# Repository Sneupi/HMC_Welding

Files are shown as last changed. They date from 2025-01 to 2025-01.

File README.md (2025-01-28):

# Description

Repo for HMC welding project.

Code is arranged into three files (1 for each device). Arranged as a PlatformIO project for any Pro Mini or UNO (ATMega328P) boards. File `src/main.cpp` indicates which device is to-be-flashed.

Breakout PCBs are located in `kicad`, made with KiCad (8.0) software.

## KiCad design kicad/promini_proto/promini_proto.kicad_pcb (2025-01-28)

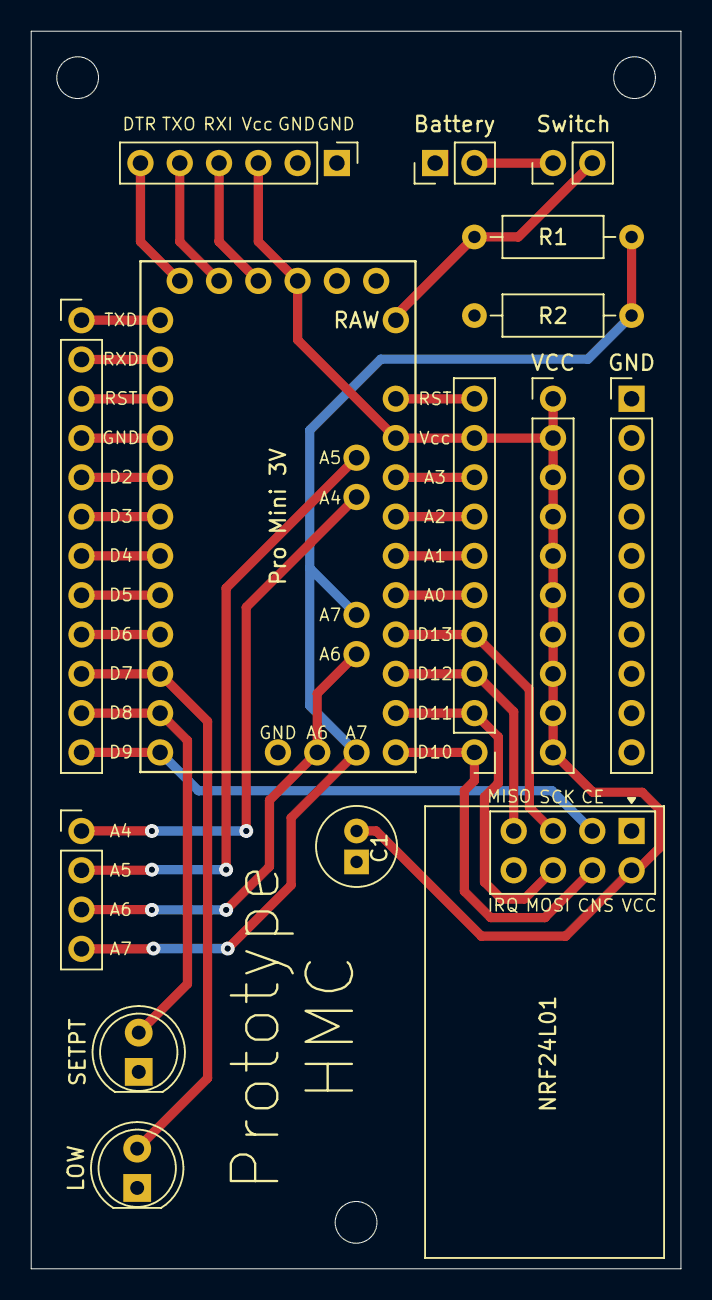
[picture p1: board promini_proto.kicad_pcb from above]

Board: 4 copper layers, 42.0 x 80.0 mm, 15 parts (0 on the bottom side), 31 nets.

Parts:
Battery: Conn_01x02; PinHeader_1x02_P2.54mm_Vertical
C1: C_Polarized; C_Radial_D5.0mm_H11.0mm_P2.00mm
FTDI1: Conn_01x06; PinHeader_1x06_P2.54mm_Vertical
GND: Conn_01x10; PinHeader_1x10_P2.54mm_Vertical
JBottom1: Conn_01x04; PinHeader_1x04_P2.54mm_Vertical
JLeft1: Conn_01x12; PinHeader_1x12_P2.54mm_Vertical
JRight1: Conn_01x10; PinHeader_1x10_P2.54mm_Vertical
LOW: LED; LED_D5.0mm
NRF24L01: NRF24L01_Breakout; nRF24L01_Breakout
Pro Mini 3V: Pro_Mini; Pro_Mini_Universal
R1, R2: R; R_Axial_DIN0207_L6.3mm_D2.5mm_P10.16mm_Horizontal
SETPT: LED; LED_D5.0mm
Switch: Conn_01x02; PinHeader_1x02_P2.54mm_Vertical
VCC: Conn_01x10; PinHeader_1x10_P2.54mm_Vertical

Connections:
A0: JRight1.5, Pro Mini 3V.26 (PC0/A0)
A1: JRight1.6, Pro Mini 3V.25 (PC1/A1)
A2: JRight1.7, Pro Mini 3V.24 (PC2/A2)
A3: JRight1.8, Pro Mini 3V.23 (PC3/A3)
A4: JBottom1.1, Pro Mini 3V.31 (PA4)
A5: JBottom1.2, Pro Mini 3V.32 (PA5)
A6: JBottom1.3, Pro Mini 3V.33 (PA6)
A7: JBottom1.4, Pro Mini 3V.34 (PA7), R1.2, R2.1
D2: JLeft1.5, Pro Mini 3V.11 (PD2)
D3: JLeft1.6, Pro Mini 3V.12 (PD3)
D4: JLeft1.7, Pro Mini 3V.13 (PD4)
D5: JLeft1.8, Pro Mini 3V.14 (PD5)
D6: JLeft1.9, Pro Mini 3V.15 (PD6)
D7: JLeft1.10, LOW.2 (A), Pro Mini 3V.16 (PD7)
D8: JLeft1.11, Pro Mini 3V.17 (PB0), SETPT.2 (A)
D9: JLeft1.12, NRF24L01.3 (CE), Pro Mini 3V.18 (PB1)
D10: JRight1.1, NRF24L01.4 (~CSN), Pro Mini 3V.30 (PB2)
DTR: FTDI1.6, Pro Mini 3V.6 (DTR-CBL)
GND: Battery.1, C1.2, FTDI1.1, FTDI1.2, GND.1, GND.2, GND.3, GND.4, GND.5, GND.6, GND.7, GND.8, GND.9, GND.10, JLeft1.4, LOW.1 (K), NRF24L01.1 (GND), Pro Mini 3V.1 (GND), Pro Mini 3V.2 (GND), Pro Mini 3V.10 (GND), R2.2, SETPT.1 (K)
MISO: JRight1.3, NRF24L01.7 (MISO), Pro Mini 3V.28 (PB4)
MOSI: JRight1.2, NRF24L01.6 (MOSI), Pro Mini 3V.29 (PB3)
unnamed: Battery.2, Switch.1
RAW: Pro Mini 3V.19 (RAW), R1.1, Switch.2
RST: JRight1.10, Pro Mini 3V.21 (RESET)
RST1: JLeft1.3, Pro Mini 3V.9 (RESET)
RX1: FTDI1.4, Pro Mini 3V.4 (RX1-CBL)
RX_D1: JLeft1.2, Pro Mini 3V.8 (RX_D0)
SCK: JRight1.4, NRF24L01.5 (SCK), Pro Mini 3V.27 (PB5)
TX0: FTDI1.5, Pro Mini 3V.5 (TX0-CBL)
TX_D0: JLeft1.1, Pro Mini 3V.7 (TX0_D1)
Vcc: C1.1, FTDI1.3, JRight1.9, NRF24L01.2 (VCC), Pro Mini 3V.3 (Vcc-CBL), Pro Mini 3V.22 (Vcc), VCC.1, VCC.2, VCC.3, VCC.4, VCC.5, VCC.6, VCC.7, VCC.8, VCC.9, VCC.10

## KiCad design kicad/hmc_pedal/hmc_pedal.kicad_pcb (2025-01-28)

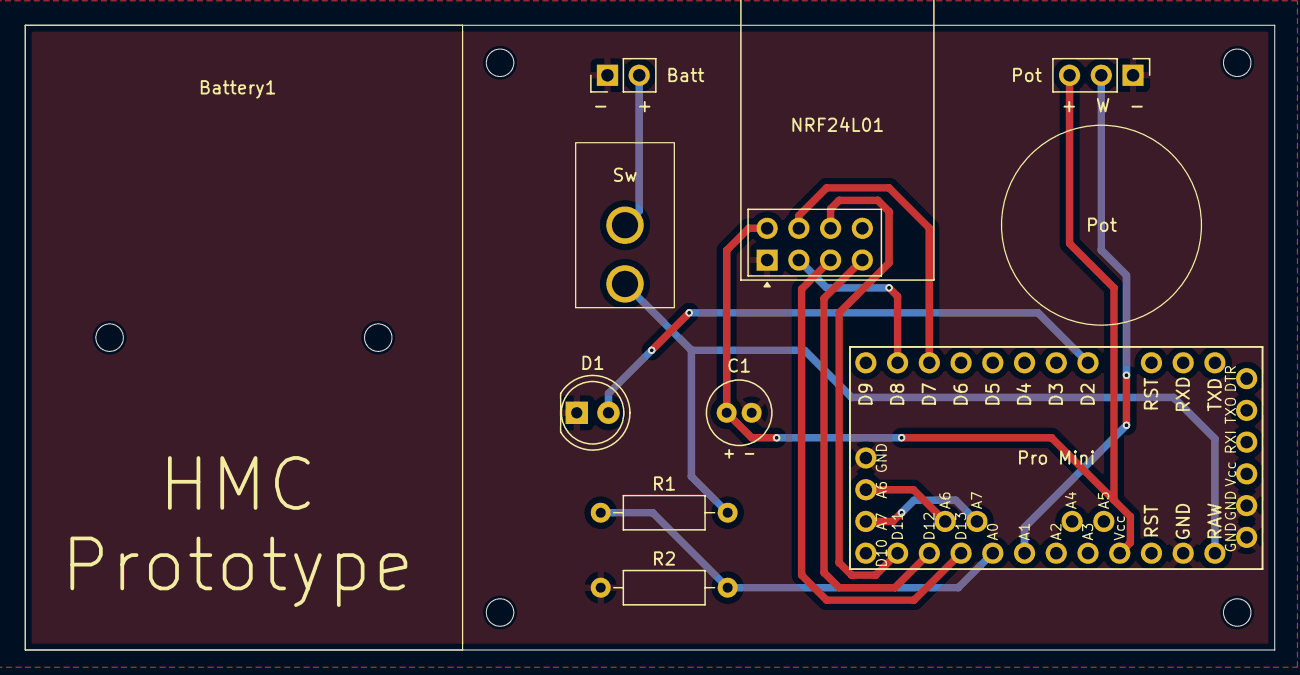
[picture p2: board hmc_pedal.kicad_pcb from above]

Board: 4 copper layers, 100.0 x 50.0 mm, 9 parts (0 on the bottom side), 12 nets.

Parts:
Battery1: Conn_01x02; PinHeader_1x02_P2.54mm_Vertical
C1: C_Polarized; C_Radial_D5.0mm_H11.0mm_P2.00mm
D1: LED; LED_D5.0mm
NRF24L01: NRF24L01_Breakout; nRF24L01_Breakout
Pot: Conn_01x03; PinHeader_1x03_P2.54mm_Vertical
Pro Mini: Pro_Mini; Pro_Mini_Universal
R1, R2: R; R_Axial_DIN0207_L6.3mm_D2.5mm_P10.16mm_Horizontal
Sw: SW_SPST; SW_SPSTx01_Taiss

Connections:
A_BATT: Pro Mini.26 (PC0/A0), R1.2, R2.1
A_POT: Pot.2, Pro Mini.25 (PC1/A1)
CE: NRF24L01.3 (CE), Pro Mini.17 (PB0)
CSN: NRF24L01.4 (~CSN), Pro Mini.16 (PD7)
D_BATT: D1.2 (A), Pro Mini.11 (PD2)
GND: Battery1.1, C1.2, D1.1 (K), NRF24L01.1 (GND), Pot.1, Pro Mini.1 (GND), Pro Mini.2 (GND), Pro Mini.10 (GND), Pro Mini.20 (GND), R2.2
MISO: NRF24L01.7 (MISO), Pro Mini.28 (PB4)
MOSI: NRF24L01.6 (MOSI), Pro Mini.29 (PB3)
RAW: Pro Mini.19 (RAW), R1.1, Sw.2 (B)
SCK: NRF24L01.5 (SCK), Pro Mini.27 (PB5)
SW: Battery1.2, Sw.1 (A)
VCC: C1.1, NRF24L01.2 (VCC), Pot.3, Pro Mini.22 (Vcc)

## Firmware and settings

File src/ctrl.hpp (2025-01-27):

/*
Arduino RC Controller
*/
#include <Arduino.h>
#include <SPI.h>
#include <nRF24L01.h>
#include <RF24.h>
#include "config.h"

#define BAUD 9600
#define CE 9
#define CSN 10
#define LOWV 3.0
#define VDIV 2.0 // 1/n divider
#define LED_SET 8
#define LED_BAT 7
#define BATT A7
#define POT_SCL A0
#define BUT_UP 3
#define BUT_DN 2

RF24 radio(CE, CSN); // nRF24L01 (CE, CSN)
byte set_max = 255;
byte set_min = 0;
bool set_max_flag = false;
bool set_min_flag = false;

void setup()
{
    Serial.begin(9600);

    pinMode(BUT_UP, INPUT_PULLUP); // Button UP
    pinMode(BUT_DN, INPUT_PULLUP); // Button DOWN
    pinMode(LED_BAT, OUTPUT);      // Low Battery LED
    pinMode(LED_SET, OUTPUT);      // Setpoint LED

    digitalWrite(LED_BAT, HIGH);
    digitalWrite(LED_SET, HIGH);
    delay(500); // Test LED on boot
    digitalWrite(LED_BAT, LOW);
    digitalWrite(LED_SET, LOW);

    radio.begin();
    radio.openReadingPipe(1, ADDRESS1);
    radio.openWritingPipe(ADDRESS2);
    radio.setAutoAck(false);
    radio.setDataRate(RF24_250KBPS);
    radio.setPALevel(RF24_PA_LOW);
    radio.startListening();

    Serial.println("CTRL Init OK");
}
void loop()
{
    // Check incoming data
    if (radio.available())
    {
        byte val;
        radio.read(&val, sizeof(byte));

        // update setpoints if flag
        if (set_max_flag)
        {
            set_max = val;
            set_max_flag = false;
        }
        if (set_min_flag)
        {
            set_min = val;
            set_min_flag = false;
        }

        // update setpoint led
        digitalWrite(LED_SET, val <= set_min || val >= set_max);

        // thresh & scale value
        if (val < set_min) val = set_min;
        if (val > set_max) val = set_max;
        val = map(val, set_min, set_max, 0, 255);
        val = map(analogRead(POT_SCL), 0, 1023, 0, val);
        // Send data
        radio.stopListening();
        radio.write(&val, sizeof(val));
        radio.startListening();
    }

    // Setpoint
    if (digitalRead(BUT_UP) == LOW && !set_max_flag)
    {
        set_max_flag = true;
        set_min_flag = false;
    }
    if (digitalRead(BUT_DN) == LOW && !set_min_flag)
    {
        set_min_flag = true;
        set_max_flag = false;
    }

    // Check battery
    float voltage = analogRead(BATT) * (5.00 / 1023.00) * VDIV;
    digitalWrite(LED_BAT, voltage < LOWV); // HIGH if true
}

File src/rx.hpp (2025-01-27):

/*
Arduino RC Receiver
*/
#include <Arduino.h>
#include <SPI.h>
#include <nRF24L01.h>
#include <RF24.h>
#include <Servo.h>
#include "config.h"

#define BAUD 9600
#define CE 9
#define CSN 10
#define TIMEOUT 500
#define SERVO 2
#define RELAY 3

Servo servo;
RF24 radio(CE, CSN); // nRF24L01 (CE, CSN)
unsigned long lastReceiveTime = 0;
unsigned long currentTime = 0;
byte pot;

void resetData()
{
    pot = 0;
}

void updateServo()
{
    int angle = map(pot, 0, 255, 0, 180);
    servo.write(angle);
}

void updateRelay()
{
    digitalWrite(RELAY, pot > 0);
}

void setup()
{   
    Serial.begin(BAUD);
    servo.attach(SERVO); // init servo
    pinMode(RELAY, OUTPUT); // init relay

    radio.begin();
    radio.openReadingPipe(0, ADDRESS2);
    radio.setAutoAck(false);
    radio.setDataRate(RF24_250KBPS);
    radio.setPALevel(RF24_PA_LOW);
    radio.startListening(); //  Set the module as receiver
    resetData();
    
    updateRelay();
    updateServo();
    Serial.println("RX Init OK");
}

void loop()
{
    // Check lost connection
    currentTime = millis();
    if (currentTime - lastReceiveTime > TIMEOUT)
    {
        // Reset, avoid unwanted behavior
        resetData();
    }
    // Check incoming data
    if (radio.available())
    {
        radio.read(&pot, sizeof(byte));
        lastReceiveTime = millis();
    }
    // Update Relay & Servo
    updateRelay();
    updateServo();
    // Debug
    Serial.println(pot);
}

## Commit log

2024-12-31 add servo lib
2024-12-31 rx relay & servo code
2025-01-01 5v mini config
2025-01-03 update device select
2025-01-28 kicad pcb files
    [freerouting.dsn, hmc_pedal.kicad_pcb, hmc_pedal.kicad_sch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]
